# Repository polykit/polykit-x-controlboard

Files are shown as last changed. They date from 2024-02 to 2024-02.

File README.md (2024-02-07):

# Polykit X8 Controlboard

_THIS IS NOT A FINISHED PRODUCT IN ANY WAY AND STILL UNDER HEAVY DEVELOPMENT - USE AT YOUR OWN RISK!_

This repository contains Kicad schematics and PCB layout of a control board for a polyphonic synthesizer.

There is a video playlist on the design process https://makertube.net/w/p/3N2fRjXwT2SfAUv2VkMy3e

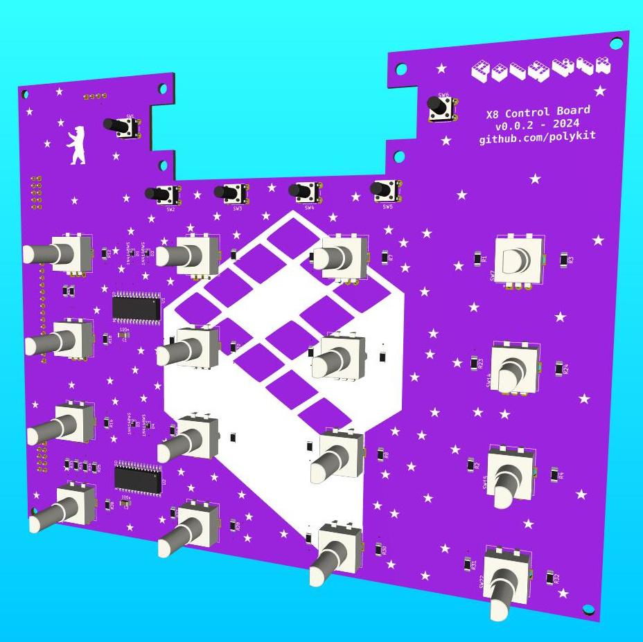
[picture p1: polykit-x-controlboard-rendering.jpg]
Polykit X8 Main Board Rendering


Related repositories:

* Voice Card: https://github.com/polykit/polykit-x-voice-card
* Main Board: https://github.com/polykit/polykit-x-mainboard
* Input Board: _soon_
* Software: _soon_
* Power Supply: https://github.com/polykit/eurorack-psu

## BOM
|Reference|Value |Footprint |Comment |Qty|
|---|---|---|---|---|
|C1, C2 |100n |Capacitor_SMD:C_1206_3216Metric | |2  |
|D1-D4 |1N4148WS |Diode_SMD:D_SOD-323 | |4  |
|J1 |MCU_BOARD |Connector_PinHeader_2.54mm:PinHeader_1x16_P2.54mm_Vertical |optional, when used as MIDI controller|1  |
|J2 |X8_I2C_POWER  |Connector_IDC:IDC-Header_2x05_P2.54mm_Vertical | |1  |
|J3 |X8_EXT_DIGITAL|Connector_IDC:IDC-Header_2x05_P2.54mm_Vertical | |1  |
|J4 |DISPLAY |Connector_PinHeader_2.54mm:PinHeader_1x04_P2.54mm_Vertical | |1  |
|R1-R34 |10k |Resistor_SMD:R_1206_3216Metric_Pad1.30x1.75mm_HandSolder | |34 |
|SW1-SW6  |SW_Push |Button_Switch_THT:SW_PUSH_6mm_H13mm | |6  |
|SW7-SW22 |RotaryEncoder |Rotary_Encoder:RotaryEncoder_Bourns_Vertical_PEC12R-3xxxF-Nxxxx|without switch |16 |
|U1, U2 |MCP23017_SO |Package_SO:SOIC-28W_7.5x17.9mm_P1.27mm | |2  |

## References

https://www.ti.com/lit/an/slva704/slva704.pdf

https://github.com/horfee/kicad-packages3D/tree/master/Rotary_Encoder.3dshapes

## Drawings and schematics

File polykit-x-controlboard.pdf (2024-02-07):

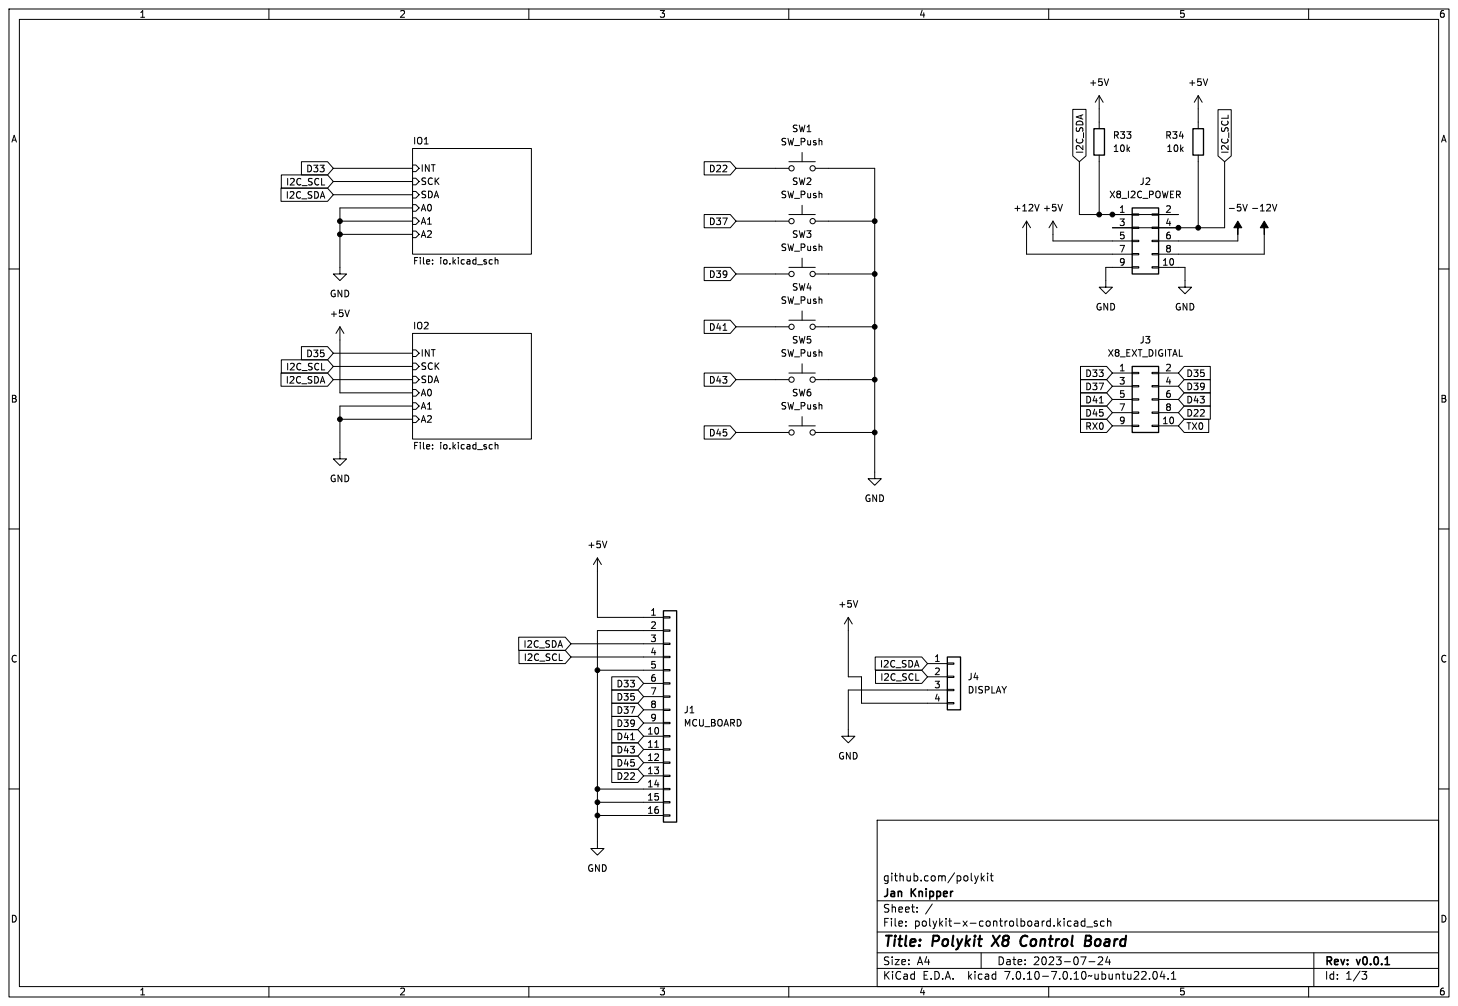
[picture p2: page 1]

Id: 1/3 Title: Polykit X8 Control Board

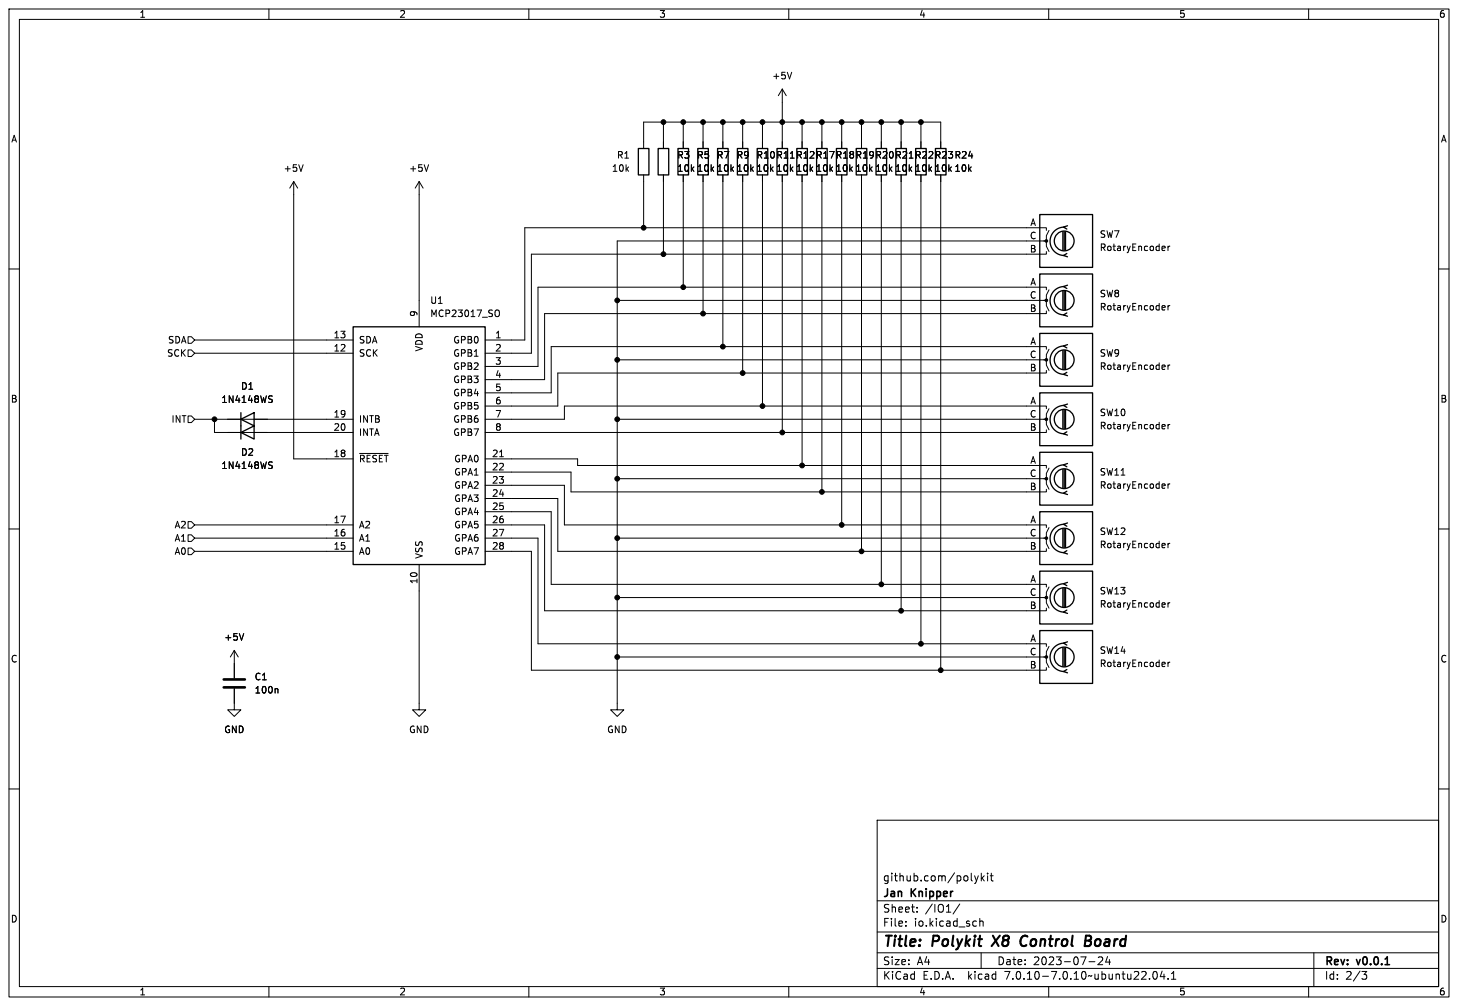
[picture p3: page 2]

Id: 2/3 Title: Polykit X8 Control Board

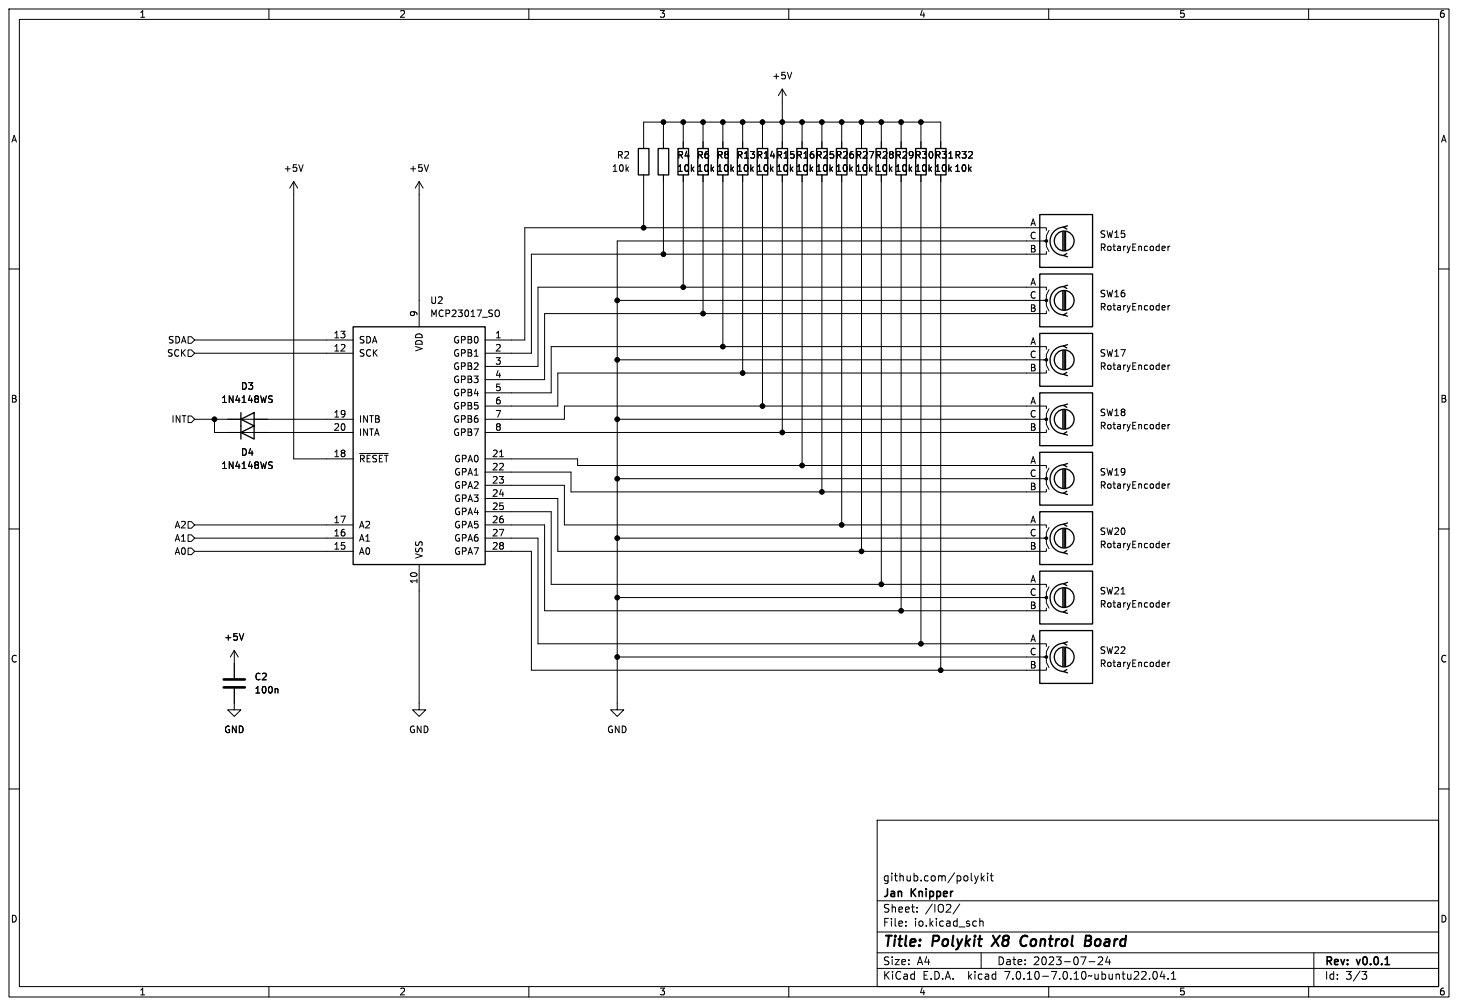
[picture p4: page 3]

Id: 3/3 Title: Polykit X8 Control Board

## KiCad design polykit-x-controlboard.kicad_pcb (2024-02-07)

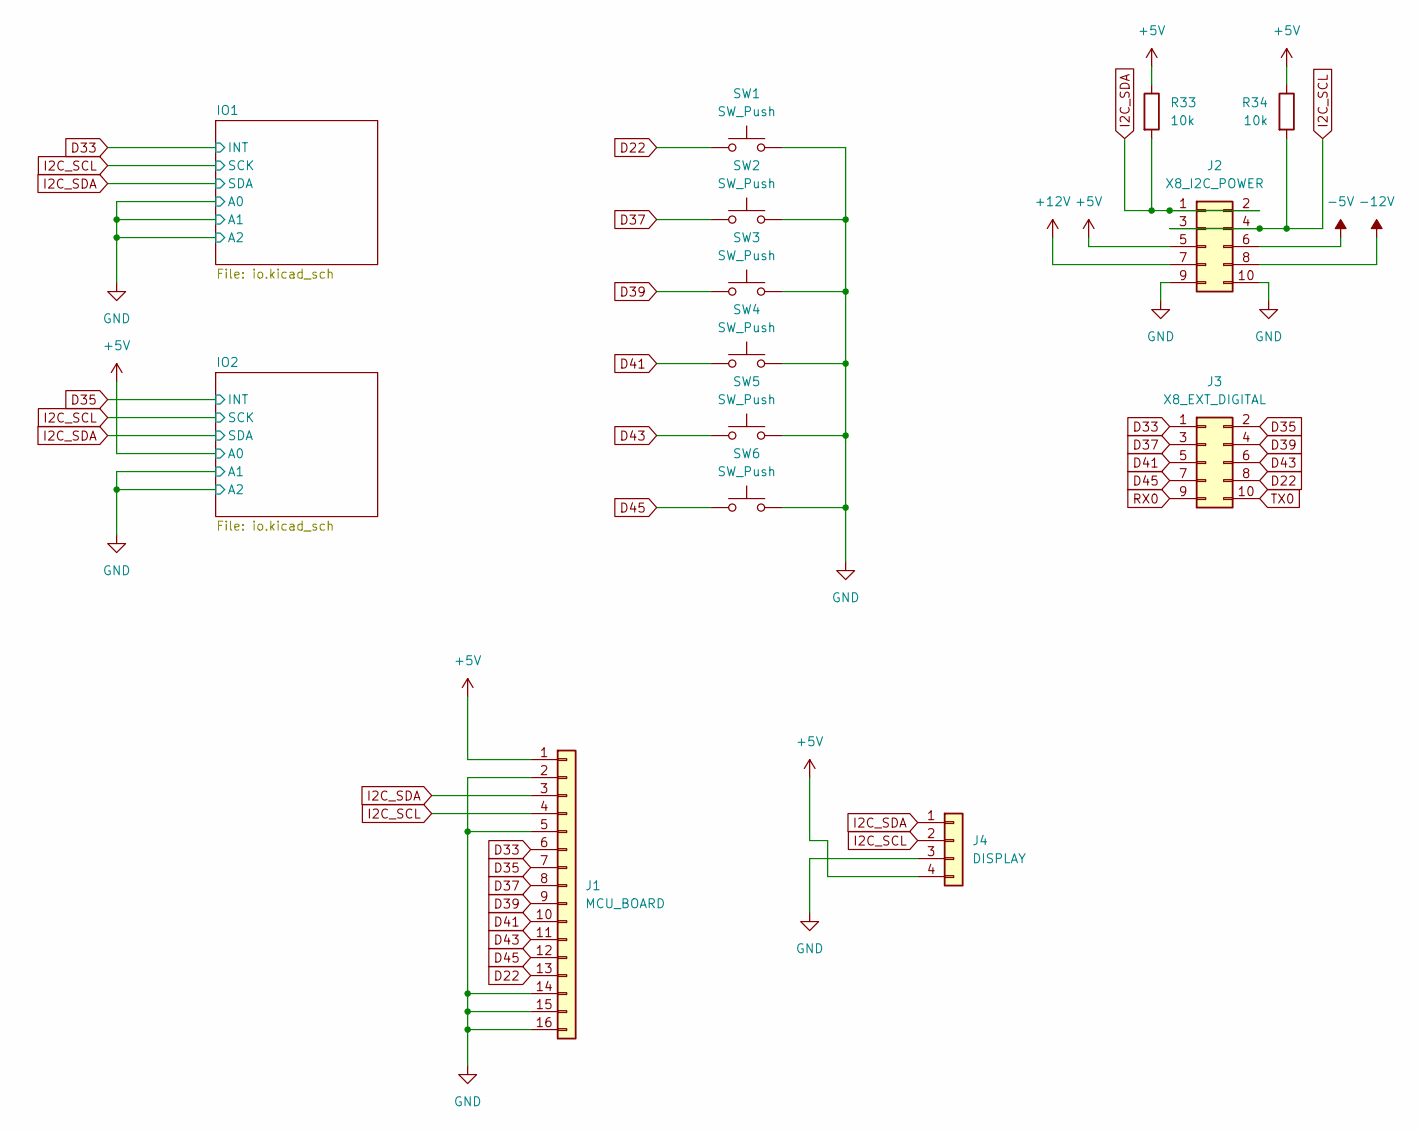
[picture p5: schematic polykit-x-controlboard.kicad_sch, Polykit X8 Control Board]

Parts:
J1: MCU_BOARD; PinHeader_1x16_P2.54mm_Vertical
J2: X8_I2C_POWER; IDC-Header_2x05_P2.54mm_Vertical
J3: X8_EXT_DIGITAL; IDC-Header_2x05_P2.54mm_Vertical
J4: DISPLAY; PinHeader_1x04_P2.54mm_Vertical
R33, R34: 10k; R_1206_3216Metric_Pad1.30x1.75mm_HandSolder
SW1, SW2, SW3, SW4, SW5, SW6: SW_Push; SW_PUSH_6mm_H13mm

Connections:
+5V: J1.1, J2.5, J4.4, R33.1, R34.1; also elsewhere on the board
+12V: J2.7
-5V: J2.6
-12V: J2.8
D22: J1.13, J3.8, SW1.1
D33: J1.6, J3.1; also elsewhere on the board
D35: J1.7, J3.2; also elsewhere on the board
D37: J1.8, J3.3, SW2.1
D39: J1.9, J3.4, SW3.1
D41: J1.10, J3.5, SW4.1
D43: J1.11, J3.6, SW5.1
D45: J1.12, J3.7, SW6.1
GND: J1.2, J1.5, J1.14, J1.15, J1.16, J2.9, J2.10, J4.3, SW1.2, SW2.2, SW3.2, SW4.2, SW5.2, SW6.2; also elsewhere on the board
I2C_SCL: J1.4, J2.3, J2.4, J4.2, R34.2; also elsewhere on the board
I2C_SDA: J1.3, J2.1, J2.2, J4.1, R33.2; also elsewhere on the board
RX0: J3.9
TX0: J3.10

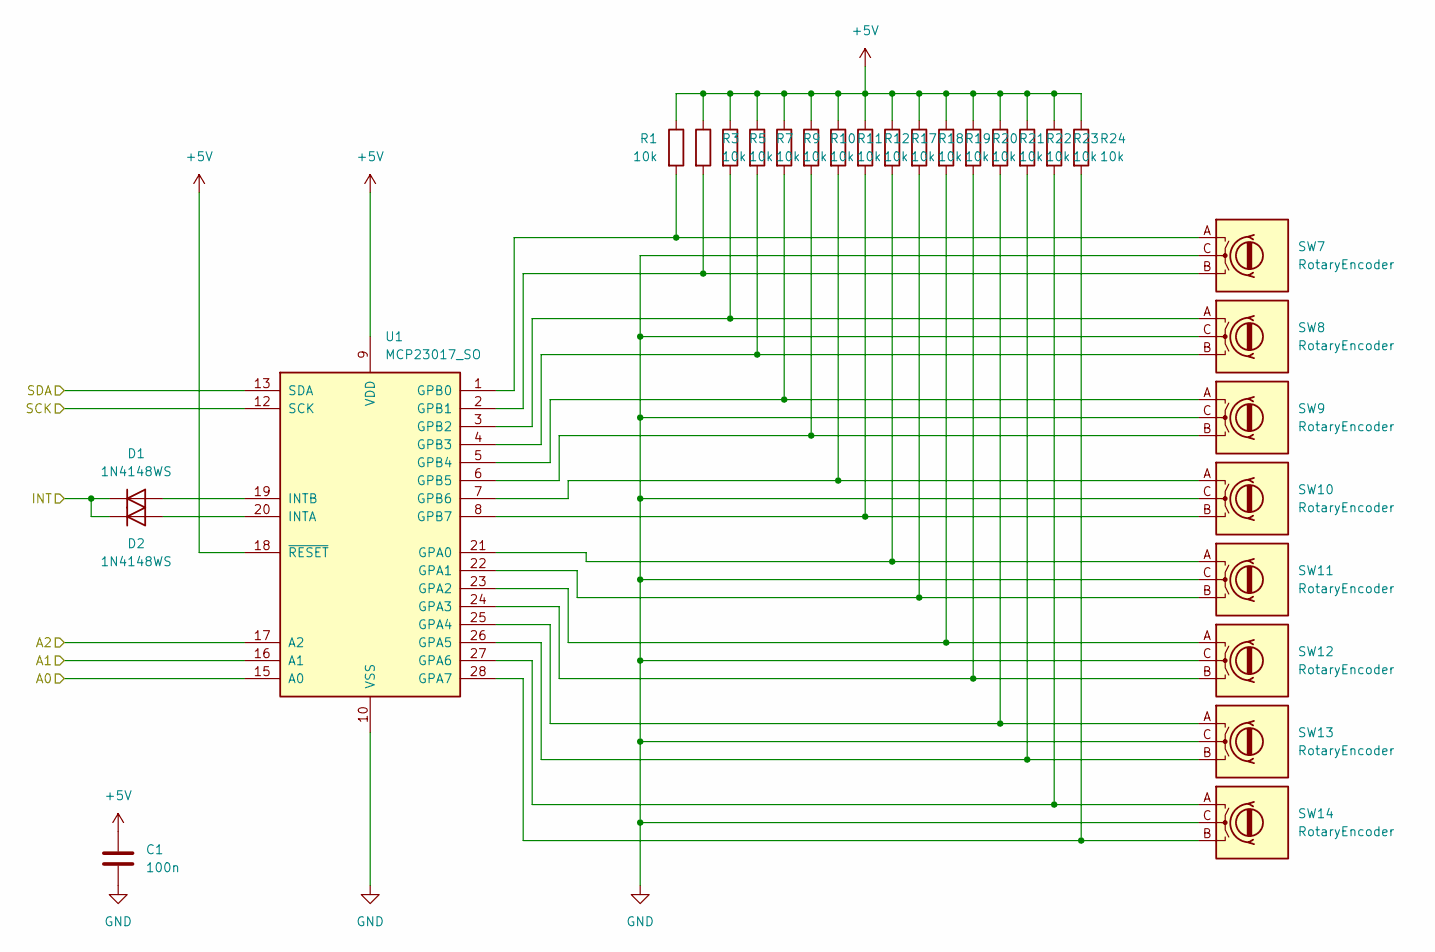
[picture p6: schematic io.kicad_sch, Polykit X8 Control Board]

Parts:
C1: 100n; C_1206_3216Metric
D1, D2: 1N4148WS; D_SOD-323
R1, R3, R5, R7, R9, R10, R11, R12, R17, R18, R19, R20, R21, R22, R23, R24: 10k; R_1206_3216Metric_Pad1.30x1.75mm_HandSolder
SW7, SW8, SW9, SW10, SW11, SW12, SW13, SW14: RotaryEncoder; RotaryEncoder_Bourns_Vertical_PEC12R-3xxxF-Nxxxx
U1: MCP23017_SO; SOIC-28W_7.5x17.9mm_P1.27mm

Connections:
+5V: C1.1, R1.1, R3.1, R5.1, R7.1, R9.1, R10.1, R11.1, R12.1, R17.1, R18.1, R19.1, R20.1, R21.1, R22.1, R23.1, R24.1, U1.9 (VDD), U1.18 (~RESET); also elsewhere on the board
D33: D1.1 (K), D2.1 (K); also elsewhere on the board
GND: C1.2, SW7.C, SW8.C, SW9.C, SW10.C, SW11.C, SW12.C, SW13.C, SW14.C, U1.10 (VSS), U1.15 (A0), U1.16 (A1), U1.17 (A2); also elsewhere on the board
I2C_SCL: U1.12 (SCK); also elsewhere on the board
I2C_SDA: U1.13 (SDA); also elsewhere on the board
unnamed: D1.2 (A), U1.19 (INTB)
unnamed: D2.2 (A), U1.20 (INTA)
unnamed: R17.2, SW11.A, U1.21 (GPA0)
unnamed: R18.2, SW11.B, U1.22 (GPA1)
unnamed: R19.2, SW12.A, U1.23 (GPA2)
unnamed: R20.2, SW12.B, U1.24 (GPA3)
unnamed: R21.2, SW13.A, U1.25 (GPA4)
unnamed: R22.2, SW13.B, U1.26 (GPA5)
unnamed: R23.2, SW14.A, U1.27 (GPA6)
unnamed: R24.2, SW14.B, U1.28 (GPA7)
unnamed: R1.2, SW7.A, U1.1 (GPB0)
unnamed: R3.2, SW7.B, U1.2 (GPB1)
unnamed: R5.2, SW8.A, U1.3 (GPB2)
unnamed: R7.2, SW8.B, U1.4 (GPB3)
unnamed: R9.2, SW9.A, U1.5 (GPB4)
unnamed: R10.2, SW9.B, U1.6 (GPB5)
unnamed: R11.2, SW10.A, U1.7 (GPB6)
unnamed: R12.2, SW10.B, U1.8 (GPB7)

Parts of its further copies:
C2: 100n; C_1206_3216Metric
D3, D4: 1N4148WS; D_SOD-323
R2, R4, R6, R8, R13, R14, R15, R16, R25, R26, R27, R28, R29, R30, R31, R32: 10k; R_1206_3216Metric_Pad1.30x1.75mm_HandSolder
SW15, SW16, SW17, SW18, SW19, SW20, SW21, SW22: RotaryEncoder; RotaryEncoder_Bourns_Vertical_PEC12R-3xxxF-Nxxxx
U2: MCP23017_SO; SOIC-28W_7.5x17.9mm_P1.27mm

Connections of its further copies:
+5V: C2.1, R2.1, R4.1, R6.1, R8.1, R13.1, R14.1, R15.1, R16.1, R25.1, R26.1, R27.1, R28.1, R29.1, R30.1, R31.1, R32.1, U2.9 (VDD), U2.15 (A0), U2.18 (~RESET); also elsewhere on the board
D35: D3.1 (K), D4.1 (K); also elsewhere on the board
GND: C2.2, SW15.C, SW16.C, SW17.C, SW18.C, SW19.C, SW20.C, SW21.C, SW22.C, U2.10 (VSS), U2.16 (A1), U2.17 (A2); also elsewhere on the board
I2C_SCL: U2.12 (SCK); also elsewhere on the board
I2C_SDA: U2.13 (SDA); also elsewhere on the board
unnamed: D3.2 (A), U2.19 (INTB)
unnamed: D4.2 (A), U2.20 (INTA)
unnamed: R25.2, SW19.A, U2.21 (GPA0)
unnamed: R26.2, SW19.B, U2.22 (GPA1)
unnamed: R27.2, SW20.A, U2.23 (GPA2)
unnamed: R28.2, SW20.B, U2.24 (GPA3)
unnamed: R29.2, SW21.A, U2.25 (GPA4)
unnamed: R30.2, SW21.B, U2.26 (GPA5)
unnamed: R31.2, SW22.A, U2.27 (GPA6)
unnamed: R32.2, SW22.B, U2.28 (GPA7)
unnamed: R2.2, SW15.A, U2.1 (GPB0)
unnamed: R4.2, SW15.B, U2.2 (GPB1)
unnamed: R6.2, SW16.A, U2.3 (GPB2)
unnamed: R8.2, SW16.B, U2.4 (GPB3)
unnamed: R13.2, SW17.A, U2.5 (GPB4)
unnamed: R14.2, SW17.B, U2.6 (GPB5)
unnamed: R15.2, SW18.A, U2.7 (GPB6)
unnamed: R16.2, SW18.B, U2.8 (GPB7)

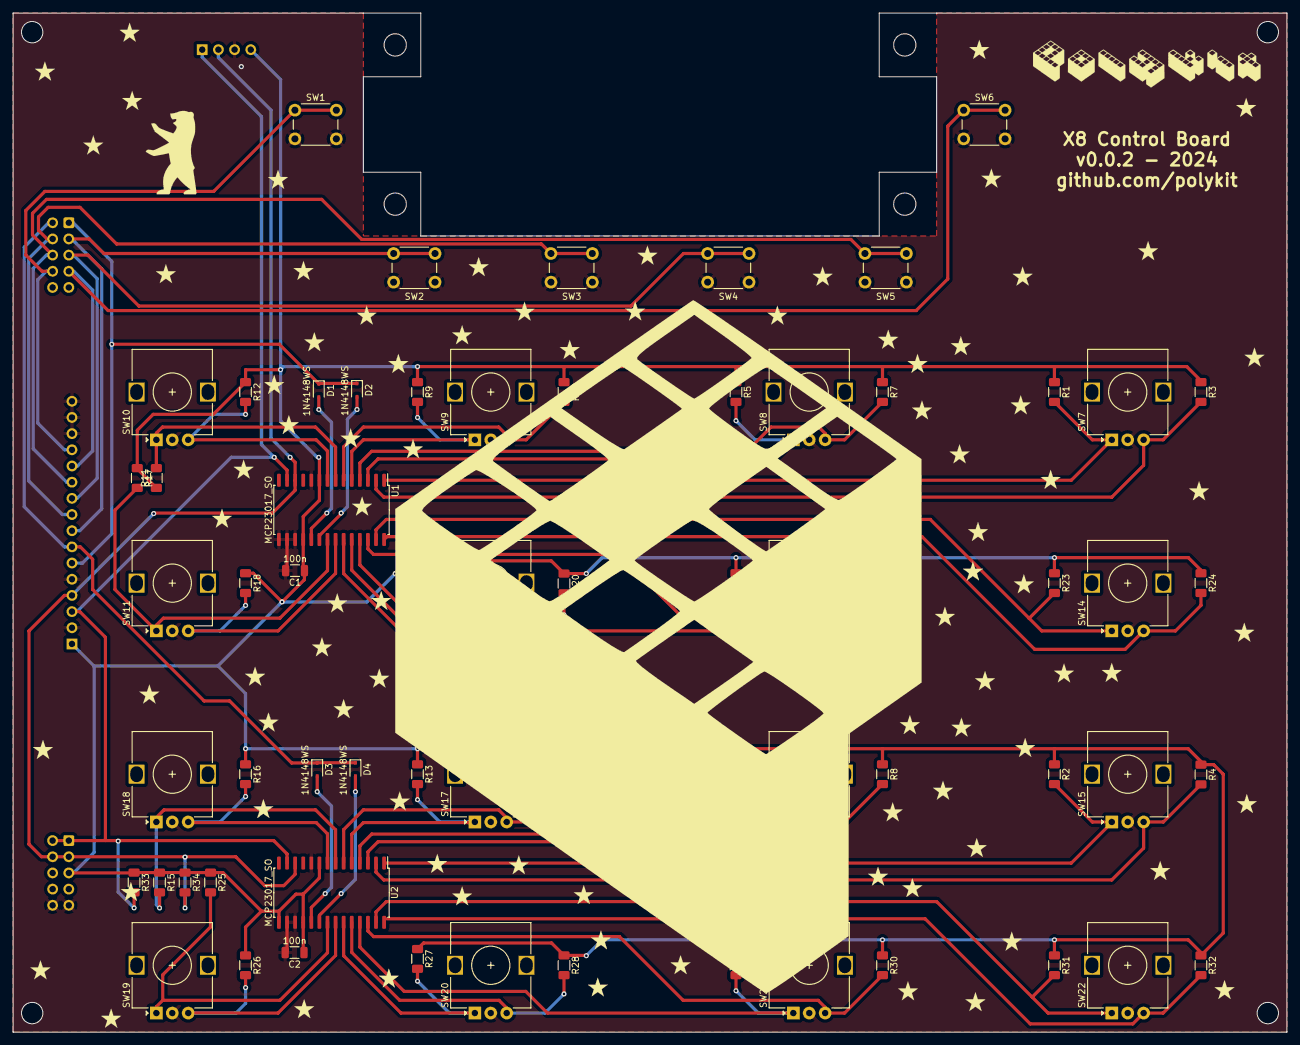
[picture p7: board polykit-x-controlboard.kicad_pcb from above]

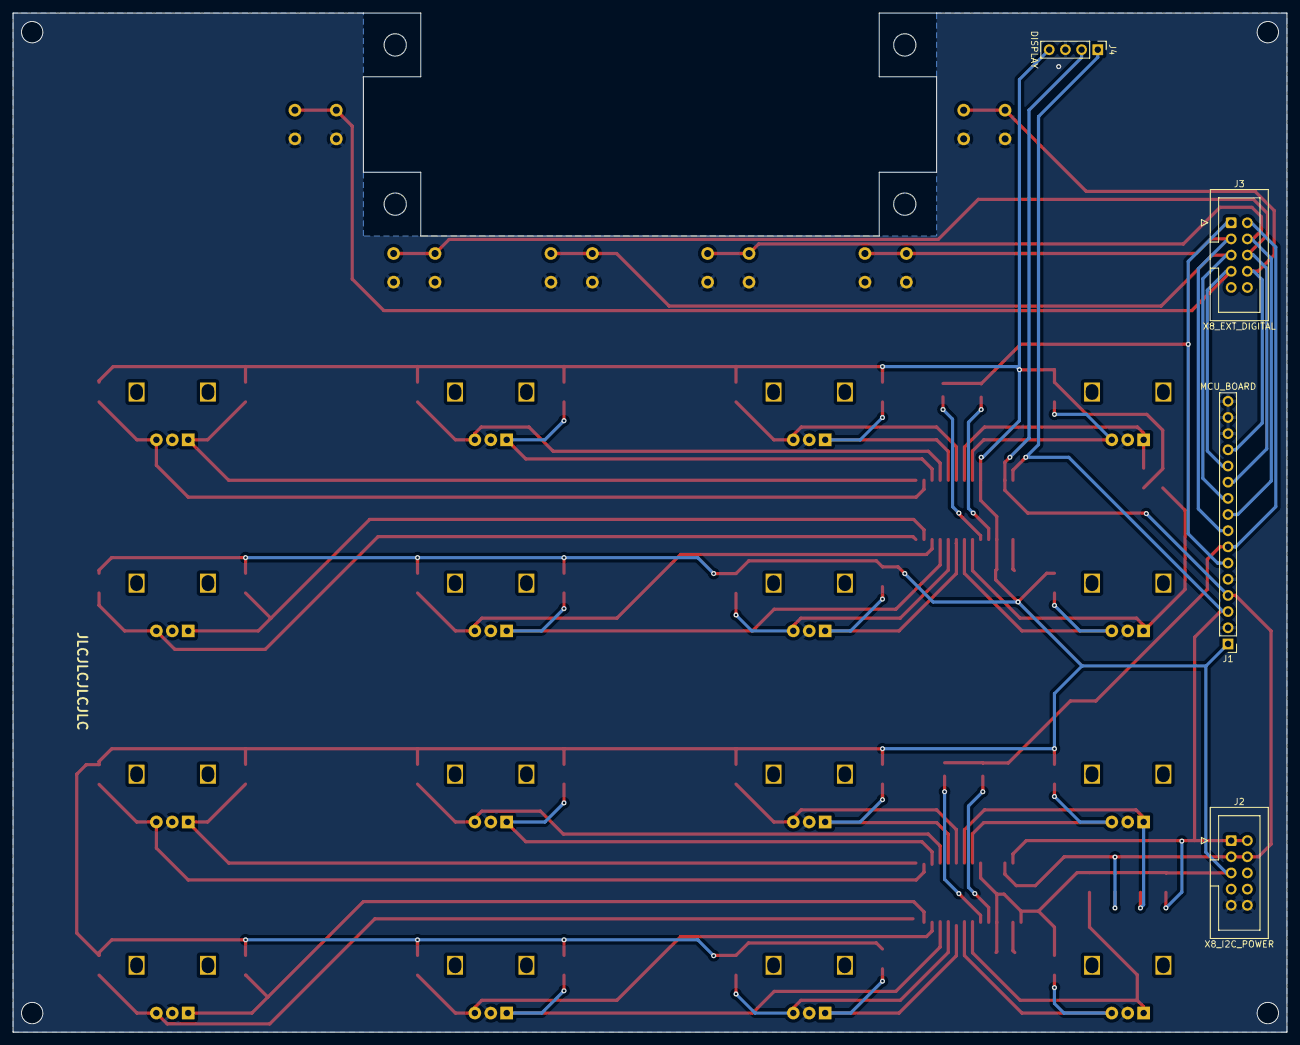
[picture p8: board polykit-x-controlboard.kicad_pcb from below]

Board: 2 copper layers, 200.0 x 160.0 mm, 68 parts (4 on the bottom side), 48 nets.

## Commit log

2024-02-07 Initial import
    [io.kicad_sch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]
2024-02-07 Add bom
    [io.kicad_sch, polykit-x-controlboard.kicad_sch]
